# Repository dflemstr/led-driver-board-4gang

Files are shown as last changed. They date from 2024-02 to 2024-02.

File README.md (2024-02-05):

# LED Driver Board (4-gang)

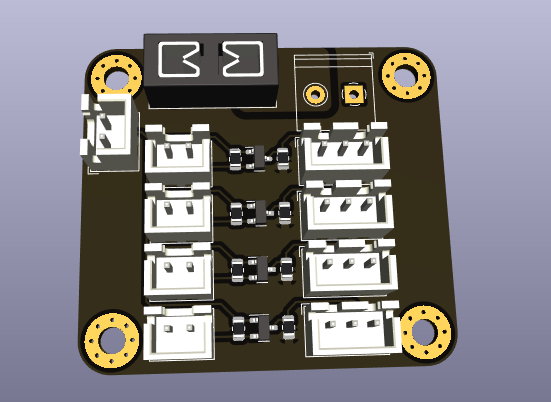
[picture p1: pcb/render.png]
PCB render


This is a simple LED driver board for 4x 5V neopixel-style LED strips, with level shifters to allow for 3.3V logic.

All of this could probably be soldered-together by hand using an off-the-shelf level shifter PCB and some wires, but
I wanted the convenience of having everything mounted to a single board.

The design also offers a shared fuse for all the LED outputs, which is a nice added benefit.  However, the fuse holder
can be skipped and replaced by a short wire if so desired.

## Tradrack mount

The `./tradrack-mount` folder contains a simple model to mount the board to an Annex Engineering TradRack, or on
the underside of any 2020 aluminium extrusion, really.  I recommend setting `Perimeters & Shell` > `Advanced` >
`No perimeters on bridge areas` > `Fill the voids with bridges` in SuperSlicer to make the mounting screw holes turn out
OK; I couldn't be bothered to model a more fancy hole.

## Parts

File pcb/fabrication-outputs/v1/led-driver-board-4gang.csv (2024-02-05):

Comment | Designator | Footprint | LCSC
JST_XH_3P | J1,J2,J3,J4 | Connector_JST:JST_XH_B3B-XH-A_1x03_P2.50mm_Vertical | C144394
JST_XH_2P | J5,J6,J7,J8,J10 | Connector_JST:JST_XH_B2B-XH-A_1x02_P2.50mm_Vertical | C158012
LED_POWER_IN | J9 | TerminalBlock_Philmore:TerminalBlock_Philmore_TB132_1x02_P5.00mm_Horizontal | C557651
BSS138 | Q1,Q2,Q3,Q4 | Package_TO_SOT_SMD:SOT-23 | C112239
10k | R1,R2,R3,R4,R5,R6,R7,R8 | Resistor_SMD:R_0805_2012Metric | C17414

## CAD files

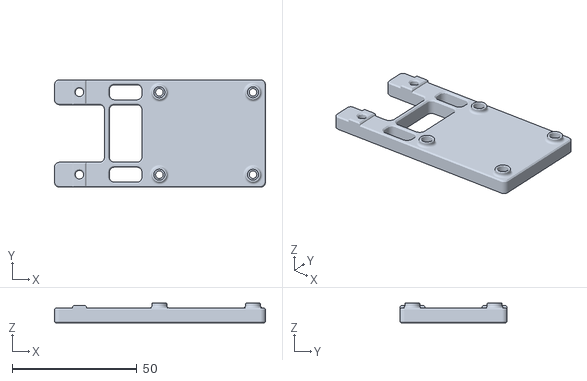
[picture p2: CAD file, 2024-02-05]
tradrack-mount/tradrack-led-board-mount-body.stl
84.5 x 43.0 x 8.00

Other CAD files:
tradrack-mount/tradrack-led-board-mount.FCStd

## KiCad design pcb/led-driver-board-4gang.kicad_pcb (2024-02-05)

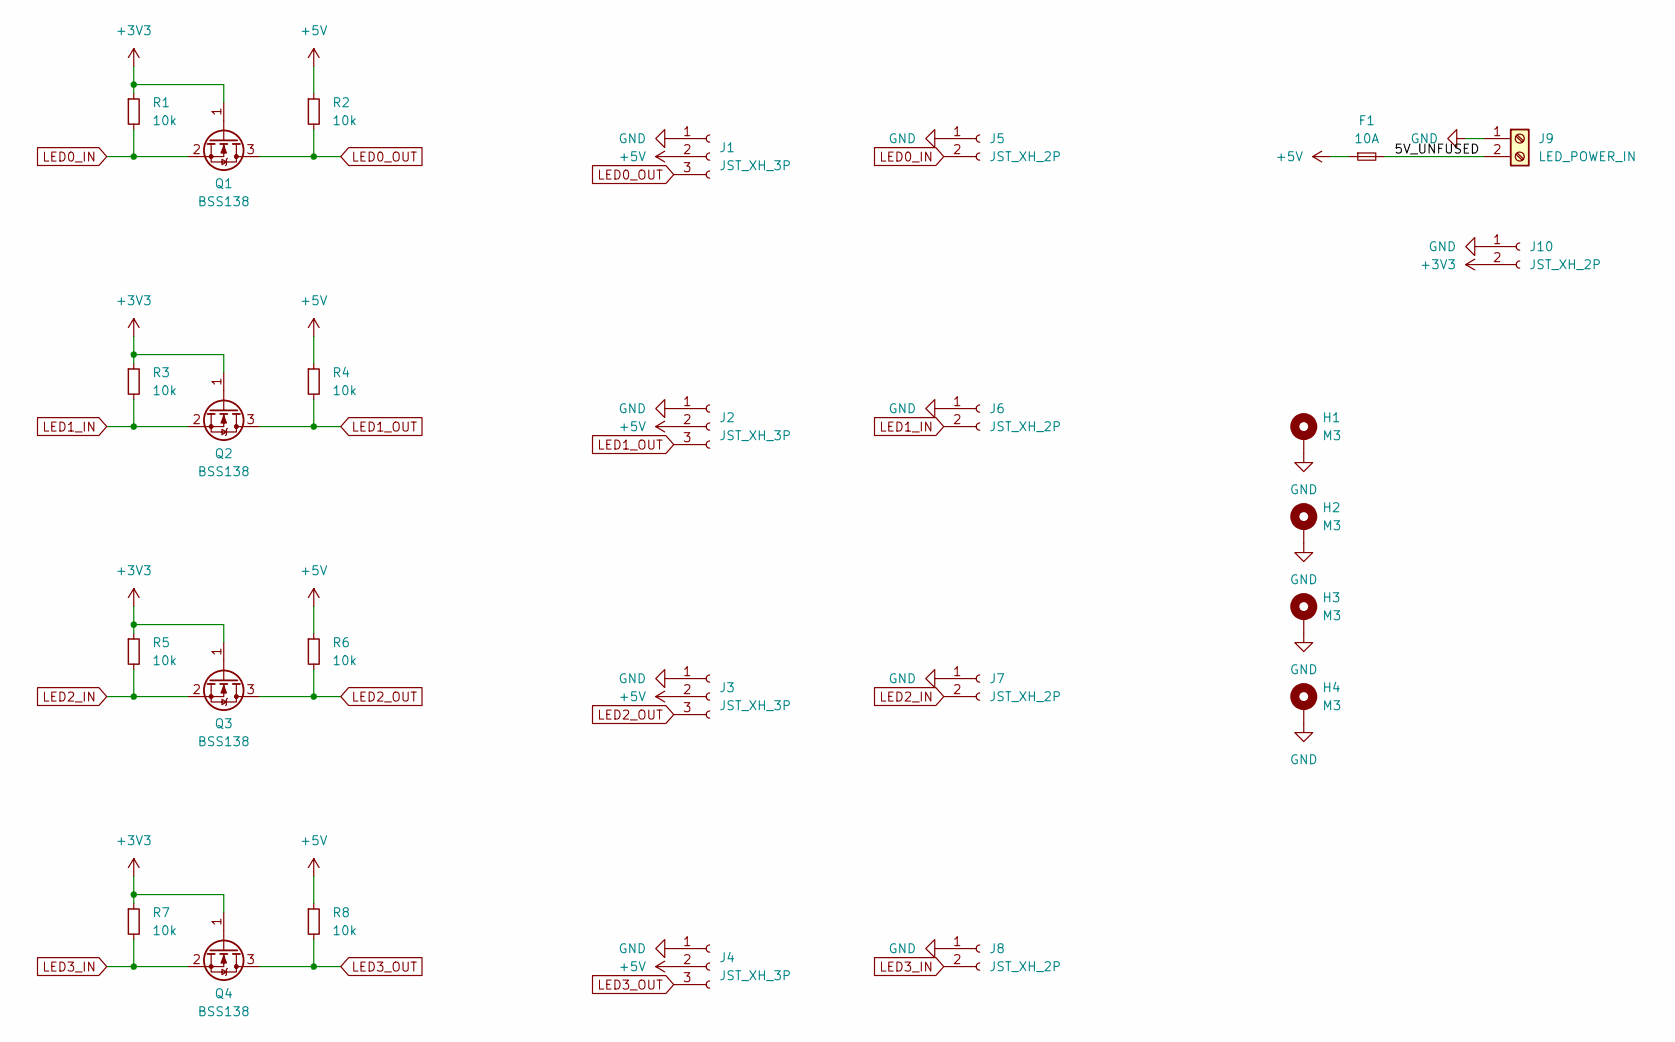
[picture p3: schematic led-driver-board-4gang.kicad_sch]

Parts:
F1: 10A; Fuseholder_Blade_Mini_Keystone_3568; LCSC C3206309
H1, H2, H3, H4: M3; MountingHole_3.2mm_M3_Pad_Via
J1, J2, J3, J4: JST_XH_3P; JST_XH_B3B-XH-A_1x03_P2.50mm_Vertical; LCSC C144394
J5, J6, J7, J8, J10: JST_XH_2P; JST_XH_B2B-XH-A_1x02_P2.50mm_Vertical; LCSC C158012
J9: LED_POWER_IN; TerminalBlock_Philmore_TB132_1x02_P5.00mm_Horizontal; LCSC C557651
Q1, Q2, Q3, Q4: BSS138; SOT-23; LCSC C112239
R1, R2, R3, R4, R5, R6, R7, R8: 10k; R_0805_2012Metric; LCSC C17414

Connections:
+3V3: J10.2, Q1.1 (G), Q2.1 (G), Q3.1 (G), Q4.1 (G), R1.1, R3.1, R5.1, R7.1
+5V: F1.1, J1.2, J2.2, J3.2, J4.2, R2.1, R4.1, R6.1, R8.1
/5V_UNFUSED: F1.2, J9.2
GND: H1.1, H2.1, H3.1, H4.1, J1.1, J2.1, J3.1, J4.1, J5.1, J6.1, J7.1, J8.1, J9.1, J10.1
LED0_IN: J5.2, Q1.2 (S), R1.2
LED0_OUT: J1.3, Q1.3 (D), R2.2
LED1_IN: J6.2, Q2.2 (S), R3.2
LED1_OUT: J2.3, Q2.3 (D), R4.2
LED2_IN: J7.2, Q3.2 (S), R5.2
LED2_OUT: J3.3, Q3.3 (D), R6.2
LED3_IN: J8.2, Q4.2 (S), R7.2
LED3_OUT: J4.3, Q4.3 (D), R8.2

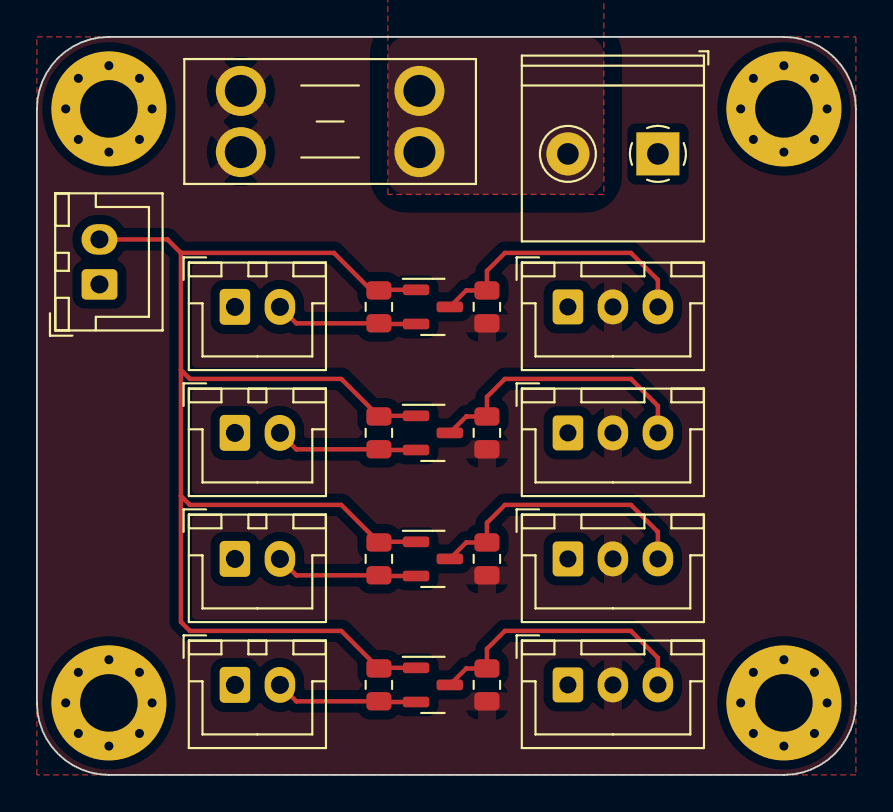
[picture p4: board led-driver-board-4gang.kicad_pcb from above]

Board: 2 copper layers, 45.5 x 41.0 mm, 27 parts (0 on the bottom side), 12 nets.

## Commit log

2024-02-05 Initial PCB and mounting solution
    [led-driver-board-4gang-B_Cu.gbr, led-driver-board-4gang-B_Mask.gbr, led-driver-board-4gang-B_Paste.gbr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]
2024-02-05 Add bit to README about the TradRack mount
